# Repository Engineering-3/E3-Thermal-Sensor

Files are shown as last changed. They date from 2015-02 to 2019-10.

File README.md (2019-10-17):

E3-Thermal Sensor
========================

E3 Thermal Sensor

This is the thermal sensor used with the Engineering^3 curriculum and RCM Control Stack. Please see [Engineering3](http://engineering3.org/) for more information on the complete RCM Control Stack project.

Repository Contents
-------------------

* **/E3-Thermal-Sensor_v1/** Eagle board/schematic files, gerbers, and BOM

Version History
---------------
* [E3-Thermal-Sensor_v1](https://github.com/Engineering-3/E3-Thermal-Sensor/tree/master/E3-Thermal-Sensor_v1)  Inital relased version v1

License Information
-------------------
Hardware is released under [Solderpad Hardware License v0.51](http://solderpad.org/licenses/SHL-0.51/).
Distributed as-is; no warranty is given.

Getting Started Help
--------------------
This is a Plug-n-Play board.

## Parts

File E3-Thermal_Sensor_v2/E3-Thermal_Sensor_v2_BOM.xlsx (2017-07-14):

E3-Touch_Sensor_v1 BOM
Item # | Qty | Ref Des | Manufacturer | Mfg Part # | Dist. Part # | Description | Package | Type
1 | 1 | C1 | Yageo (https://www.digikey.com/en/supplier-centers/y/yageo) | CC0603ZRY5V9BB104 | 311-1343-1-ND | CAP CER 0.1UF 50V Y5V 0603 | 603 | SMT
2 | 1 | U1 | Melexis Technologies NV (https://www.digikey.com/en/supplier-centers/m/melexis) | MLX90614ESF-ACF-000-TU | MLX90614ESF-ACF-000-TU-ND | SENSOR TEMP PWM SMBUS TO39 | TO39 | PTH
3 | 1 | J1 | Amphenol FCI (https://www.digikey.com/en/supplier-centers/a/amphenol) | 68016-204HLF | 609-3319-ND | CONN HEADER 4POS .100 R/A 15AU | header | PTH
 |  |  |  |  |  | BOARD SUMMARY FOR QUOTE
 |  |  |  |  |  | Unique Part Count
 |  |  |  |  |  | Total Placements
 |  |  |  |  |  | Thru Hole Placements
 |  |  |  |  |  | Has BGA Placements?

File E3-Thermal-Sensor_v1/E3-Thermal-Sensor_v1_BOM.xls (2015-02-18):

PE Thermal Sensor BOM
Applied Electronic Design, LLC
info@appliedelectronicdesign.com 612-308-3487
Reference Designator | Description | Manufacturer | Part Number | Qty
R1 | 499 Ohms, 0402, 1% | Rohm | RHM499LCT-ND | 1
J1 | 5 pin header | Molex | WM50014-03-ND | 1
C1,2 | 0.47uF | Murata | 490-3264-1-ND | 2
PCB | Printed Circuit Board |  |  | 1

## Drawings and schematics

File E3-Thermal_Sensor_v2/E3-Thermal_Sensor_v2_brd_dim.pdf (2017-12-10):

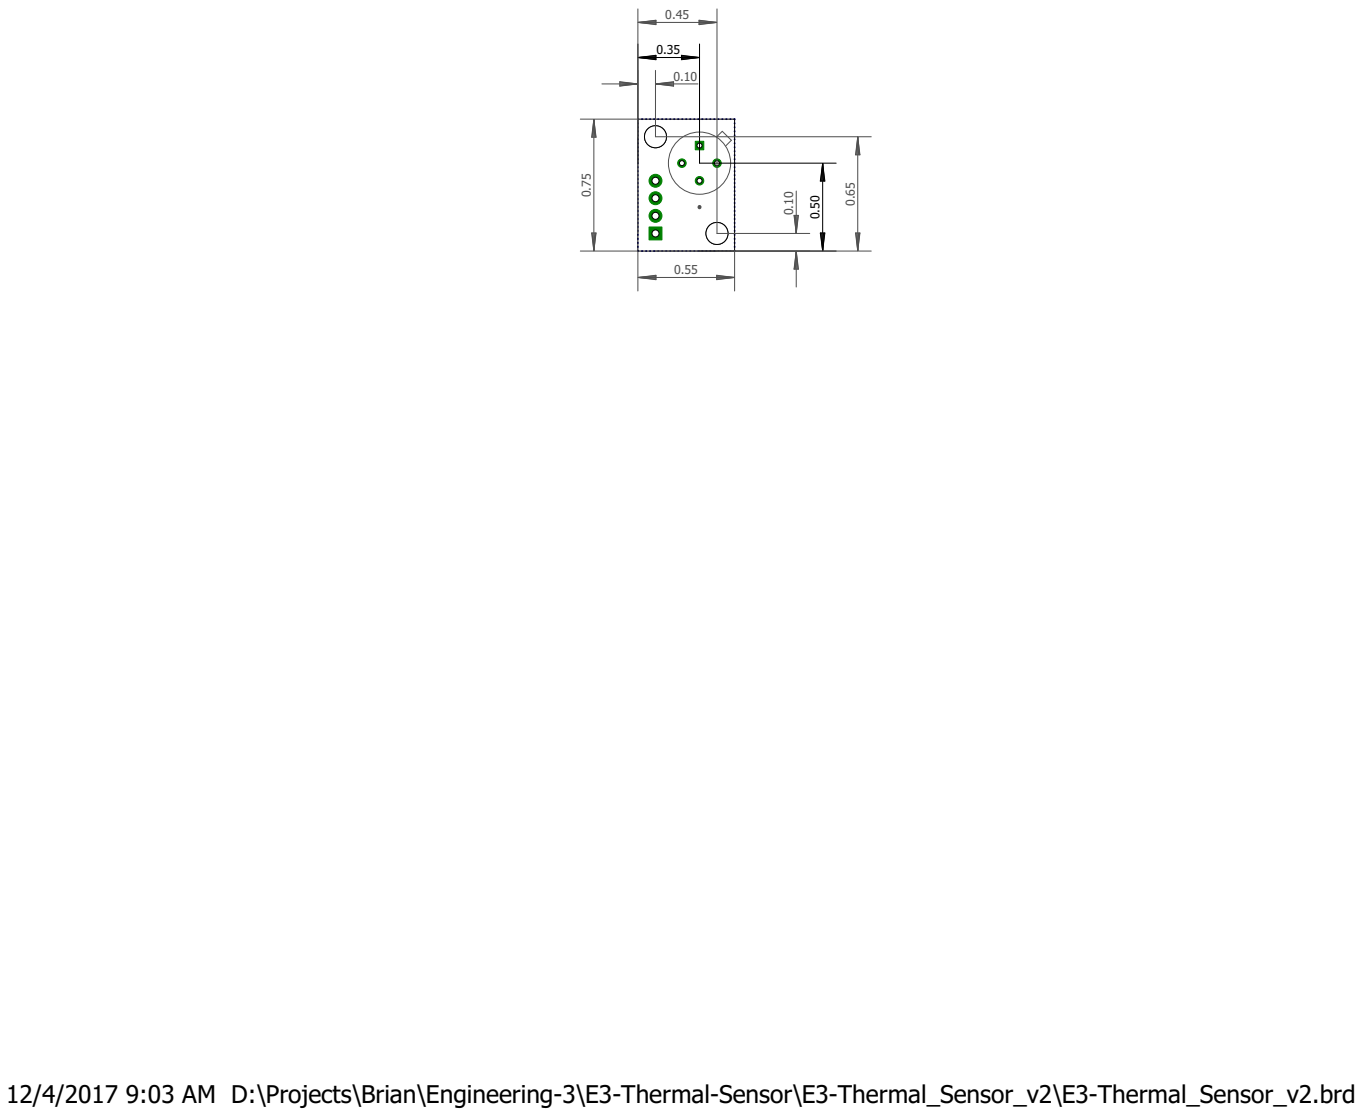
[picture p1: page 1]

12/4/2017 9:03 AM D:\Projects\Brian\Engineering-3\E3-Thermal-Sensor\E3-Thermal_Sensor_v2\E3-Thermal_Sensor_v2.brd

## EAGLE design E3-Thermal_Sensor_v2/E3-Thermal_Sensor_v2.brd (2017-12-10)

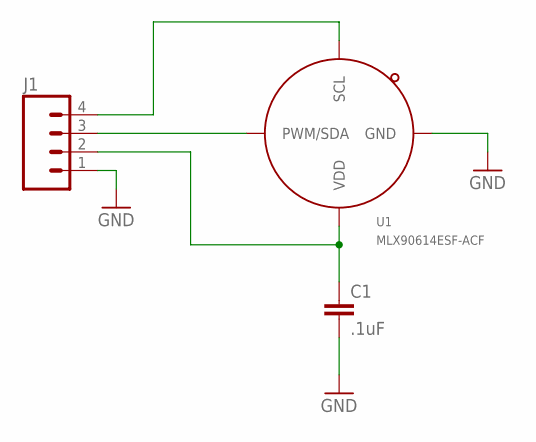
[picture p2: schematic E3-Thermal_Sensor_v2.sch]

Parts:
C1: .1uF; 0603-CAP
J1: M04PTH; 1X04
U1: MLX90614ESF-ACF; MLX90614XCF

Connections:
GND: C1.2, J1.1, U1.P4 (GND)
unnamed: C1.1, J1.2, U1.P3 (VDD)
unnamed: J1.3, U1.P2 (PWM/SDA)
unnamed: J1.4, U1.P1 (SCL)

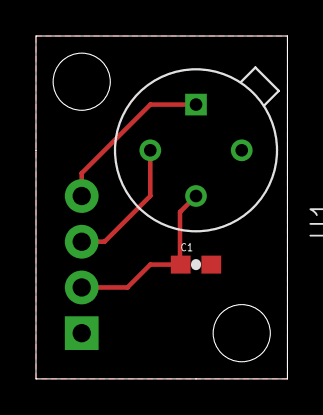
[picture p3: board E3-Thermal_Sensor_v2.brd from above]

Board: 2 copper layers, 14.0 x 19.1 mm, 3 parts (1 on the bottom side), 4 nets.

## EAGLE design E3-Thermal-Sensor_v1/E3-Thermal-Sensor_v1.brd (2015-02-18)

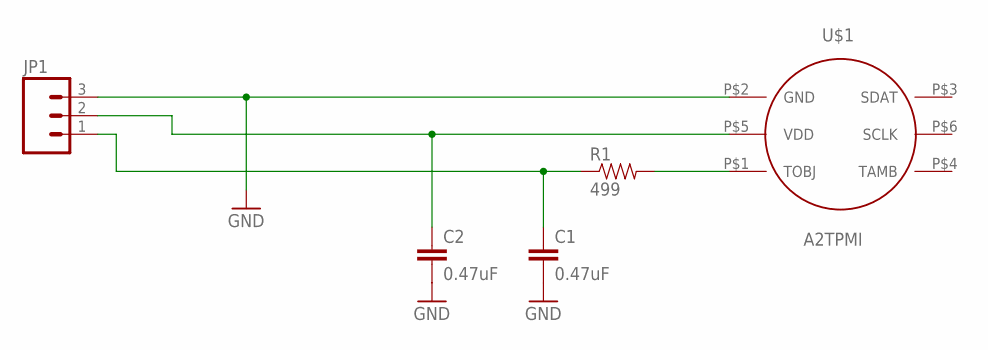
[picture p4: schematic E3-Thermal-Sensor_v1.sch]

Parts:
C1, C2: 0.47uF; C0402
JP1: M03PTH; 1X03
R1: 499; C0402
U$1: A2TPMI

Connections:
GND: C1.2, C2.2, JP1.3, U$1.P$2 (GND)
unnamed: C1.1, JP1.1, R1.1
unnamed: R1.2, U$1.P$1 (TOBJ)
unnamed: C2.1, JP1.2, U$1.P$5 (VDD)

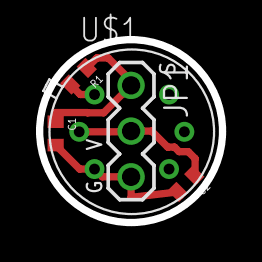
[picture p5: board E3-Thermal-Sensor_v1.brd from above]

Board: 2 copper layers, 10.2 x 10.2 mm, 5 parts (0 on the bottom side), 4 nets.

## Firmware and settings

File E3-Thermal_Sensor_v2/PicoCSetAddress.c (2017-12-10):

// This PicoC program will attempt to change the I2C (SMBus) address of a 
// thermal sensor from ADR_START to ADR_END. You must set up these two
// defines (immediately below this comment) properly. The ADR_START value
// must be the sensor's current address, and the ADR_END is what the new
// address is that you want it to move to. If you don't know what
// address your sensor is currently at, you can use the PicoCAddressScanner.c
// program to find it.
// This code will check to make sure it finds a sensor at ADR_START, then
// it will change the address,
// For a standard RCMx1 based system, don't use addresses 0x1c, 0x28, 0x29 
// or 0x30, since those are already used by devices on the I2C bus.
// If any failures are found during the process, these will be printed out
// and the process stopped.
// NOTE: After you have run this program (with no errors) you must reboot
// the sensor for it to appear on the new address.

#define ADR_START 0x5A
#define ADR_END   0x5F

// Global variables
int data;
unsigned char pec;

// Compute the CRC-8 on a single byte
unsigned char Crc8( unsigned char inCrc, unsigned char inData )
{
  unsigned char   i;
  unsigned char   data;

  data = inCrc ^ inData;

  for ( i = 0; i < 8; i++ )
  {
    if (( data & 0x80 ) != 0 )
    {
      data <<= 1;
      data ^= 0x07;
    }
    else
    {
      data <<= 1;
    }
  }
  
  return data;
}

// Compute the CRC-8 on a full 'write' transaction to the thermal sensor. Note that this
// function assumes a 3-byte write (writei2c3), and is tailored to the known packet
// structure of this type of transaction. It returns the 8-bit PEC result.
unsigned char Crc8Block(unsigned char address, unsigned char reg, unsigned int reg_value)
{
  unsigned char crc = 0;
  
  crc = Crc8(crc, (address << 1));
  crc = Crc8(crc, reg);
  crc = Crc8(crc, (reg_value & 0x000000FF));
  crc = Crc8(crc, (reg_value & 0x0000FF00) >> 8);
  
  return crc;
}

////////////////////////
// Main program flow  //
////////////////////////

// First check to see that the sensor is present on the expected address
data = readi2crs(ADR_START, 0x00);

if (data < 0)
{
  printf("ERROR: Sensor not found on START address of 0x%02x\n.", ADR_START);
}
else
{
  // We now know we have a sensor on ADR_START. First thing is to zero out its EEPROM location 0x0E
  pec = Crc8Block(ADR_START, 0x2E, 0x0000);
  data = writei2c3(ADR_START, 0x2E, ((unsigned int)pec << 16) | 0x0000);
  
  if (data < 0)
  {
    printf("ERROR: Failure to zero address of 0x%02x\n", ADR_START);
  }
  else
  {
    delay(10); // Wait for EEPROM to finish erasing

    // Write new value to location 0x0E (I2C address)
    pec = Crc8Block(ADR_START, 0x2E, ADR_END);
    data = writei2c3(ADR_START, 0x2E, ((unsigned int)pec << 16) | ADR_END);
    
    if (data < 0)
    {
      printf("ERROR: Failure to write new address of 0x%02x\n", ADR_END);
    }
    else
    {
      printf("Sensor properly moved from 0x%02x to 0x%02x\n", ADR_START, ADR_END);
      printf("Reboot sensor for it to appear at new address\n");
    }
  }
}

printf("Done\n");
exit(1);

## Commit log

2015-02-18 Initial file checkin.
    [E3-Thermal-Sensor_v1.brd, E3-Thermal-Sensor_v1.sch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]
2015-02-18 Added BOM from Jim.
    [E3-Thermal-Sensor_v1_BOM.xls]
2017-05-28 Adding new v2 of the Thermal Sensor board.
    [E3-Thermal_Sensor_v2.brd, E3-Thermal_Sensor_v2.sch]
2017-07-14 V2 of Thermal Sensor board.
    [E3-Thermal_Sensor_v2.brd, E3-Thermal_Sensor_v2.sch, E3-Thermal_Sensor_v2_BOM.xlsx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]
2017-08-07 Final version sent to fab.
    [E3-Thermal_Sensor_v2.GBL, E3-Thermal_Sensor_v2.GBO, E3-Thermal_Sensor_v2.GBP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]
2017-12-04 Added dimensions.
    [E3-Thermal_Sensor_v2.brd]
2017-12-04 Added more dimensions.
    [E3-Thermal_Sensor_v2.brd]
2017-12-10 With new test56 firmware, got Thermal Sensor address re-writing working. Use PicoCAddressScanner.c to see what address your sensor(s) are at. Use PicoCSetAddress.c to change the address of a sensor U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
2017-12-10 Updated list of no-no addresses for I2C bus.
2019-10-17 Updated address scanner PicoC program to work properly with new I2C return value.

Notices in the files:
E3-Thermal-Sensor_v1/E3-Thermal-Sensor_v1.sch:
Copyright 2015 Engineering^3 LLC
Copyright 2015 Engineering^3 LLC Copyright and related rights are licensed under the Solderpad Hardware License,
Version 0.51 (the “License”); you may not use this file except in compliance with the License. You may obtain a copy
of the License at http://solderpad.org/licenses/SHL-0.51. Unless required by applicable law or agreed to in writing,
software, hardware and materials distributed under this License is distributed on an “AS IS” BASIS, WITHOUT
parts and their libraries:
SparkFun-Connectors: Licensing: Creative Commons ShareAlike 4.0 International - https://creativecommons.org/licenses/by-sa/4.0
